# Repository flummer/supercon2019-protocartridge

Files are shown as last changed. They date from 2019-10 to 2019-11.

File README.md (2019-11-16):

# Prototyping Cartridge for the 2019 Hackaday Superconference Badge

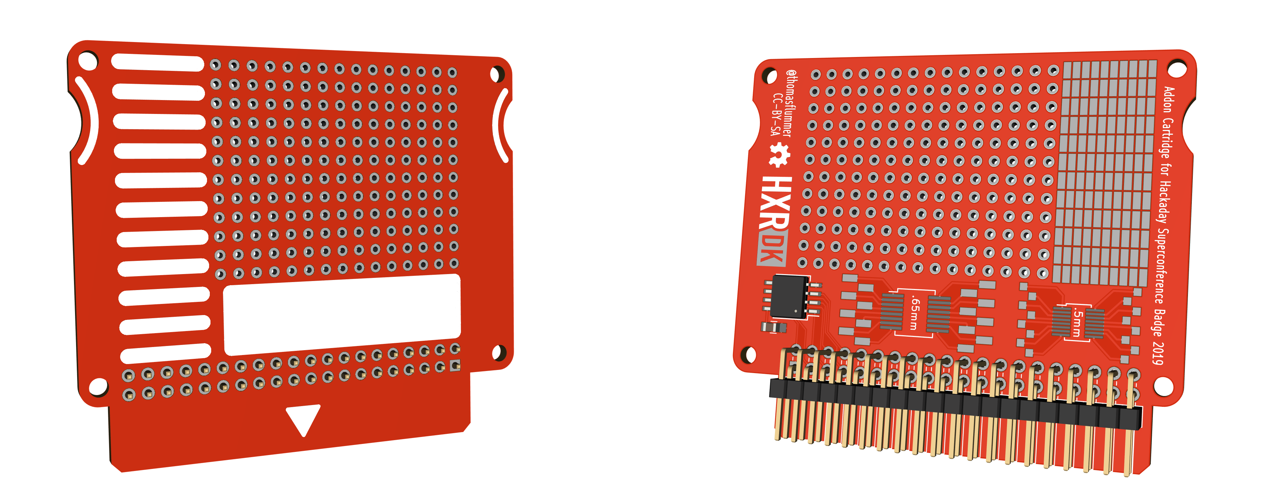
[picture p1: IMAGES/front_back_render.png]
Proto Cartridge render


This is a simple prototyping cartridge, provides both through hole and surface mount prototyping pads in addition to a few finer pitch general SMD footprints with the connections broken out to slightly larger pads. The silkscreeen also have an area where function, revision or other identifying information can be easily written with a permanent marker.

This cartridge is based on the [unofficial Superconference 2019 Badge Cartridge template](https://github.com/flummer/supercon2019-cartridgetemplate) and hence include the w25q128 SPI flash and a 100nF cap in addition to the 2x20 pin angled male pin header for the badge connection. The flash allows badge configurations and firmware specific to this cartridge to be loaded from the cartridge it self making it selfcontained.

## Version 1.2 update

This updated version fixes an error in the pin connections on the cartridge connector (the two columns was flipped for some signals).

## Special note about the original version

If you want to use a PCB based on the original version with incorrect connections, it is possible to make a hardware hack on the 20x2 angeled header, where you move the pins around and bend some of them a bit, very precisely.

## License

The contents of this repository is released under the following licence:

 * the "Creative Commons Attribution-ShareAlike 4.0 International License"
   (CC BY-SA 4.0) full text of this license is included in the LICENSE file
   and a copy can also be found at
   http://creativecommons.org/licenses/by-sa/4.0/

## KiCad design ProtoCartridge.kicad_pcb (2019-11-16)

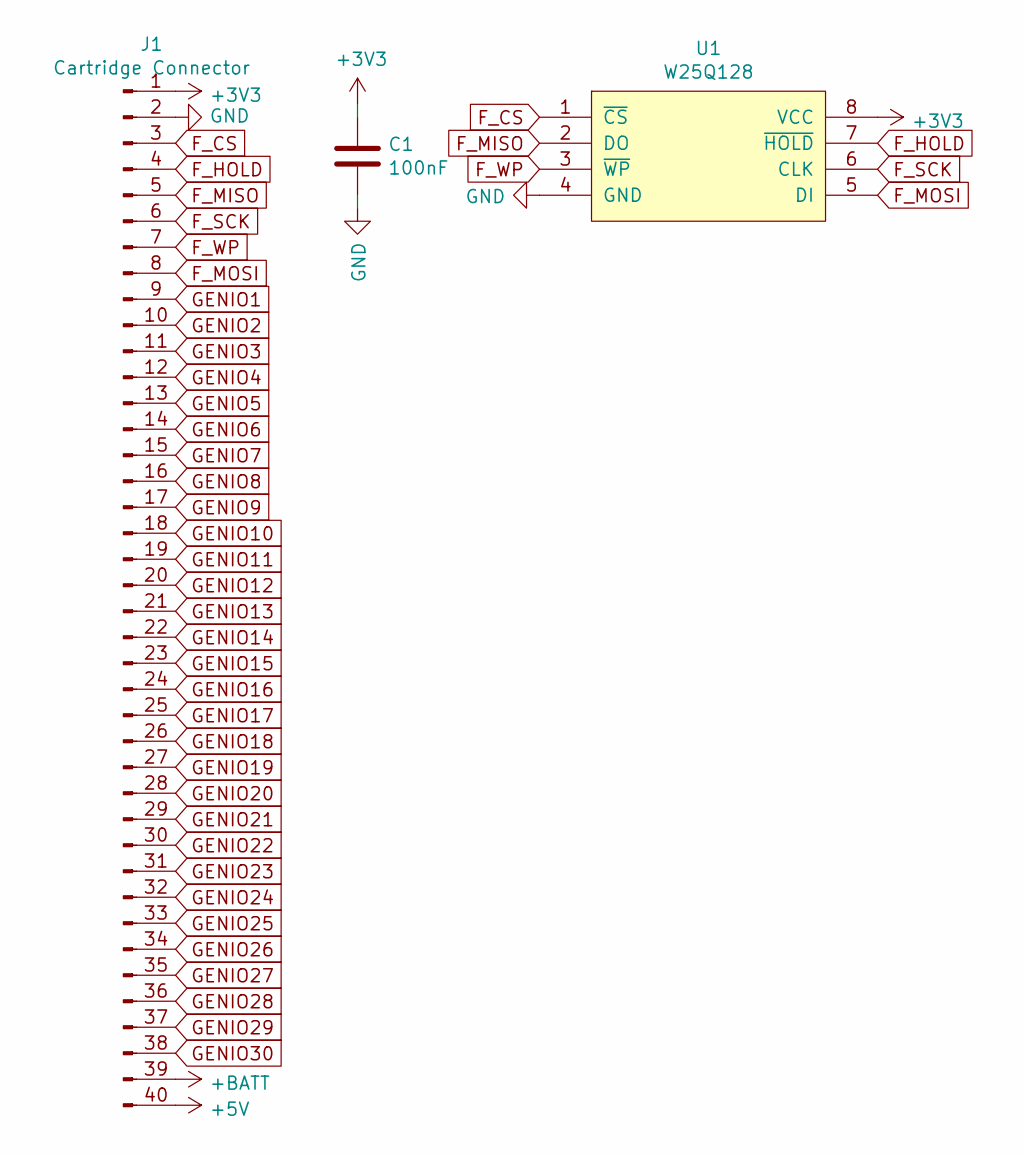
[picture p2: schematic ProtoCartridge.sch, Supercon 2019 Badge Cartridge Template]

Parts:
C1: 100nF; C_0805_HandSoldering
J1: Cartridge Connector; Supercon_Cartridge_40pin_Connector
U1: W25Q128; SO-8_5.3x6.2mm_Pitch1.27mm

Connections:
+3V3: C1.1, J1.1, U1.8 (VCC)
+5V: J1.40
+BATT: J1.39
F_CS: J1.3, U1.1 (~CS)
F_HOLD: J1.4, U1.7 (~HOLD)
F_MISO: J1.5, U1.2 (DO)
F_MOSI: J1.8, U1.5 (DI)
F_SCK: J1.6, U1.6 (CLK)
F_WP: J1.7, U1.3 (~WP)
GENIO1: J1.9
GENIO2: J1.10
GENIO3: J1.11
GENIO4: J1.12
GENIO5: J1.13
GENIO6: J1.14
GENIO7: J1.15
GENIO8: J1.16
GENIO9: J1.17
GENIO10: J1.18
GENIO11: J1.19
GENIO12: J1.20
GENIO13: J1.21
GENIO14: J1.22
GENIO15: J1.23
GENIO16: J1.24
GENIO17: J1.25
GENIO18: J1.26
GENIO19: J1.27
GENIO20: J1.28
GENIO21: J1.29
GENIO22: J1.30
GENIO23: J1.31
GENIO24: J1.32
GENIO25: J1.33
GENIO26: J1.34
GENIO27: J1.35
GENIO28: J1.36
GENIO29: J1.37
GENIO30: J1.38
GND: C1.2, J1.2, U1.4 (GND)

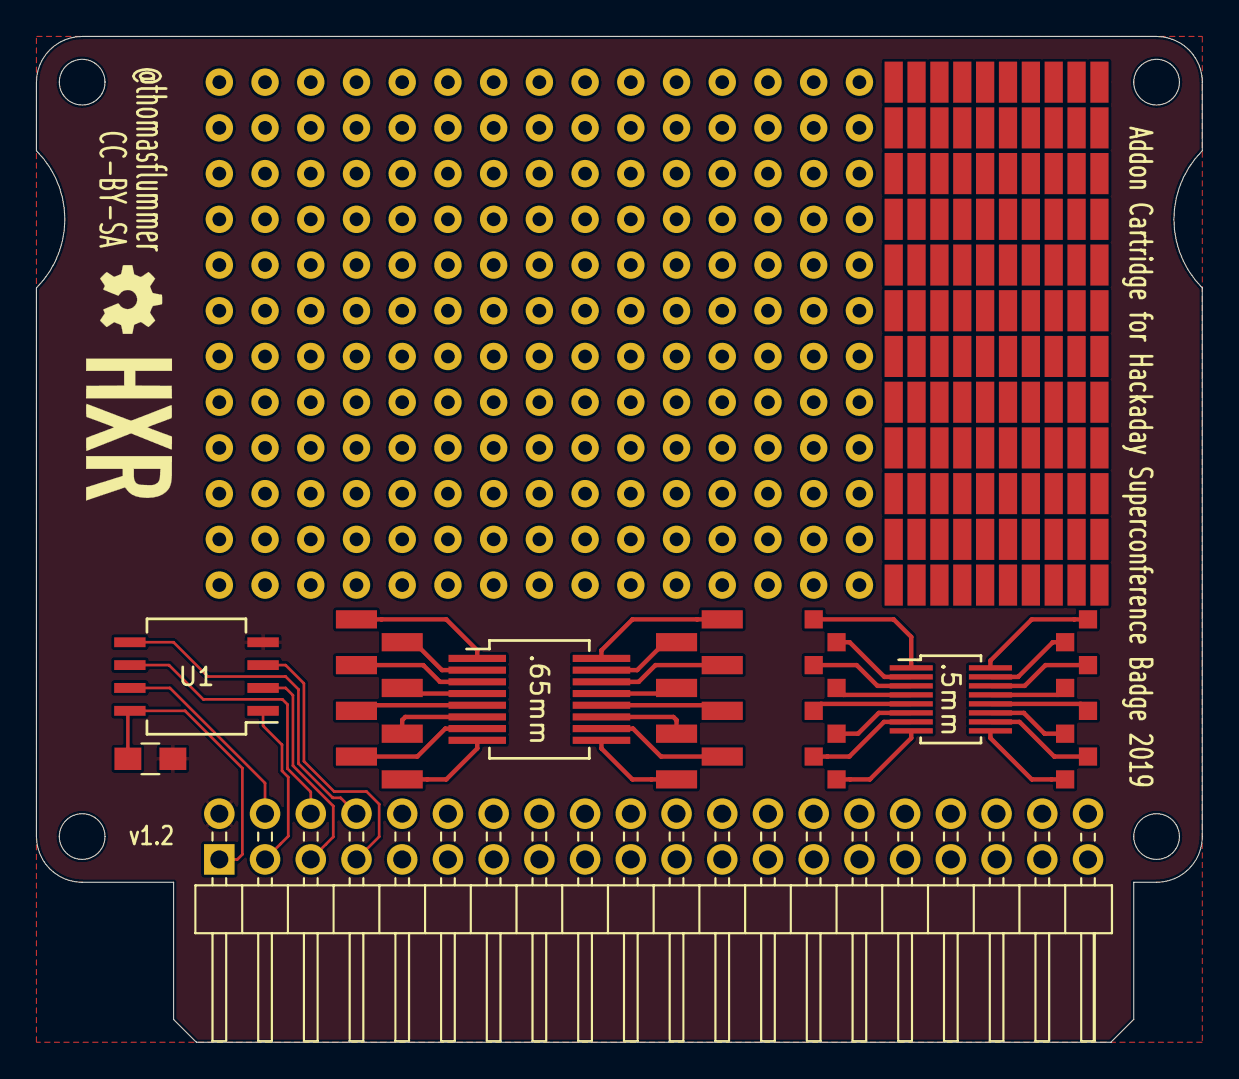
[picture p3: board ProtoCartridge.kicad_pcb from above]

Board: 2 copper layers, 64.8 x 55.9 mm, 3 parts (0 on the bottom side), 8 nets.

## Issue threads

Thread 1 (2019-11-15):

3.3V and ground are reversed!!!!

TomKeddie, 2019-11-15:
This is from this template.

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

This is from sprite_tm

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

flummer, 2019-11-16:
It's not only the VCC and GND that is flipped, also the other 6 pins for SPI to the flash and the VBAT and +5V are flipped.

flummer, 2019-11-16:
Both schematics and board files has now been updated to fix the polarity of the supply and the other mis configured pins on the cartridge connector.

TomKeddie, 2019-11-16:
Thanks, you're quicker than I am!

Closed 2019-11-16.

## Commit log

2019-10-29 First design of the Proto Cartridge
    [CartridgeTemplate.kicad_pcb, ProtoCartridge.kicad_pcb, ProtoCartridge.sch]
2019-11-16 Fixed error in cartridge connector pin assignments
    Updated to version 1.2
    [ProtoCartridge.kicad_pcb, ProtoCartridge.sch]
